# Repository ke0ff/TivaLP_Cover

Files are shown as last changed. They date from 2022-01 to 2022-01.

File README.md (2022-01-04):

# TivaLP_Cover
OpenSCAD case for the Tiva EK-TM4C123GXL LaunchPad

This is a 3-part enclosure for a TivaLP mated with a custom carrier board (AKA, shield board).  The two main parts are the Bottom and the Lid.  A third part is a clear or semi-clear light-pipe printed into the Lid.  This requires a printer with a multi-filament head in order to print as one piece.  Printing the light-pipe separately is an option, but would require a degree of manual finishing to the light-pipe and the receptor hole in the Lid.

Comments inside the OpenSCAD file describe how to create the three plots and also how to manipulate the file to produce fit-check "plots" where the pieces are all arranged in an "as assembled" fashion.

The carrier board is custom.  Details on this board are contained in the TivaLPS_HW folder.  The PCB can be fabricated using the included Gerber/NC data or the Altium database can be modified to create a custom shield board in the same form-factor as is required by the 3D case.

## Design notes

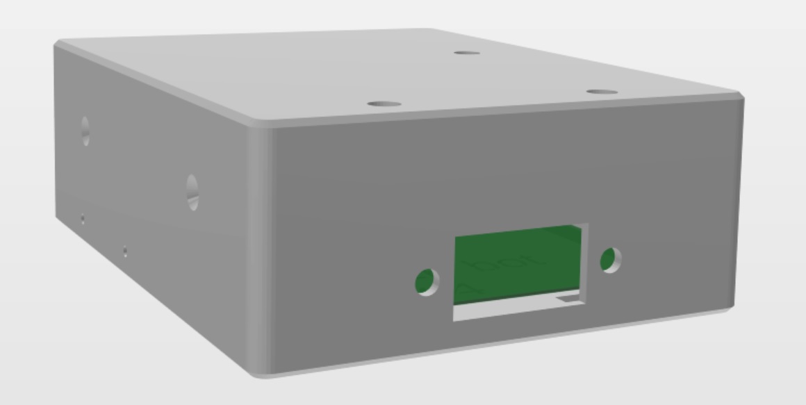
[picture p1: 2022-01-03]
TviaCaseV4.jpg

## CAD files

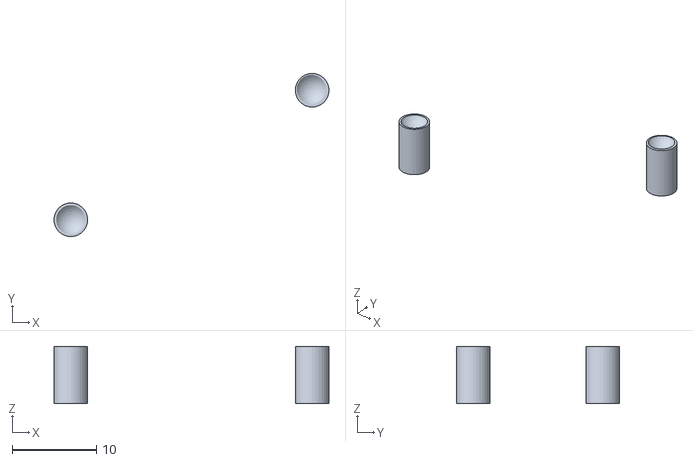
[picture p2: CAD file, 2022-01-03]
TivaCase_v4_lp.stl
32.7 x 19.4 x 6.80

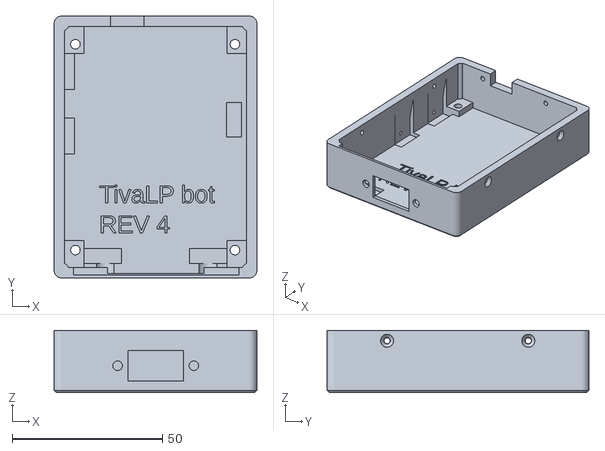
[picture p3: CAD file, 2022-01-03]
TivaCase_v4_bot.stl
67.5 x 87.2 x 20.8

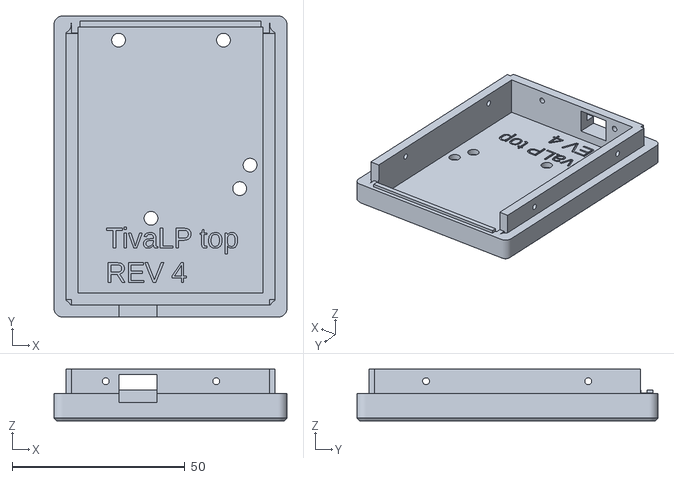
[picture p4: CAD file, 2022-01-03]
TivaCase_v4_top.stl
67.5 x 87.2 x 15.0

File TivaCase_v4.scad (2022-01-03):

// OpenSCAD 2019.05
// Tiva Case - enclosure, REV-001
// Joe Haas, KE0FF, 12/16/2021
// This is an enclosure for an EK-TM4C123GXL LaunchPad board and a custom LaunchPad
//	carrier board.
//
// Rev-004, 1/2/2022
//	Final adjustments from rev3 printing
//	added edge chamfers to top & bot at the platen faces of each part.  Softens the edge and
//		helps to counteract "elephant-foot" expansion.
//	increased depth of countersinks
//	increased size of USB port
//	removed SMA pilots for RF3&4 and replaced with "spot-face" that is 0.7mm thick
//	added another 0.5mm to lip0 for more edge clearance for LP board
//	Fixed 2-manifold rendering error in top piece (added 0.001mm to the "x" location
//		of the two corner rounds furthest from the rev text)
//
// Rev-003 (bot), 12/24/2021
//	(bot) added lid mtg countersinks (x6)
//
// Rev-003 (lid), 12/23/2021
//	(lid) added lip0 clips to remove interference
//
// Rev-002, 12/21/2021
//	incorporated fixes from first print run
//	increased lid thickness to provide room for stock LP board
//
// Rev-001, 12/16/2021
//	initial code -- copied from uxcover

//----------------------------------------------------------------------------------------------------------------------
// User defined parameters.  Modify these to suit a particular application
// NOTE: All data in this file is in mm
//----------------------------------------------------------------------------------------------------------------------
// parametric variables:

width = 67.5;
wcut = 10;
length = 87.2;
lcut = 10;
height = 20.8; //28.2;
heightl = 8;
lheight = 15;
wthick = 3.5;
wthickt = 1.5;
crad = 5;
crad2 = crad/2;
chamfer = .8;

////////////////////////////////////////////////////////////////////////////////
// Set each variable to "1" to render that part (!! only one part at a time !!).
// Set all = "0" to enable composite rendering (below).
plotlid = 1;
plotcase = 0;
plotlp = 0;

// these statements plot the 3D parts to print (one plot only, Visily!)
if(plotlid) lid(1);
if(plotlp) lid_lpipe();
if(plotcase) case();
////////////////////////////////////////////////////////////////////////////////

///////////////////////////////////////////////////////////
// Composite (debug) plot.  Places all elements in an
//	assembly orientation if no 3D parts are enabled (above)

if(!plotlid && !plotlp && !plotcase){
//	translate([0,0,0]) tiva_assy();						// launch-pad+carrier mockup for fit-check
	//
	// this is the complete case, oriented into an as-assembled view:
	difference(){
		union(){
			color("darkslategray",0.97) case();
			translate([0,length,height+heightl]) rotate([180,0,0]) color("darkslategray",1.0) lid(1);
			translate([0,length,height+heightl]) rotate([180,0,0]) lid_lpipe();
		}
//		translate([-1,-45,20.5]) cube([90,60,90]);		// cut-away viewing slice-cube (debug)
	}
}

//
//
//**************************************************
				//****************\\
				//    modules     \\
				//    follow      \\
				//****************\\
//**************************************************
//
//
///////////////
// Bottom shell

module case(){
	difference(){
		union(){
			difference(){
				union(){
					cube([width,length,height]);
//					translate([19.1,88,0]) cube([2,2,23.6]); // test-ruler
				}
 				translate([18.85,76,15.4]) cube([11,16,8.1]); 							// USB shroud
				cube([crad,crad,60], center=true);										// corner notch
				translate([width,0,0]) cube([crad,crad,60], center=true);				// corner notch
				translate([0,length,0]) cube([crad,crad,60], center=true);				// corner notch
				translate([width,length,0]) cube([crad,crad,60], center=true);			// corner notch
				translate([3.5,3.5,4.5]) cube([60.5,80.2,21.2]);						// main hog-out
				translate([3.5+6.5,3.5,4.5-2.5]) cube([60.5-13,80.2,5]);				// "Y" under PCB hog-out
				translate([3.5,3.5+6+3,4.5-2.5]) cube([60.5,80.2-12-6,5]);				// "X" under PCB hog-out
				translate([57.3,47,.5]) cube([5,11.4,4.5]);								// jtag port
				translate([width/2,length/2,11]) tiva_lp_mtg(10);						// pcb mtg holes
				translate([width/2,length/2,0]) tiva_lp_mtg_cs();						// pcb mtg hole counter-sinks
				translate([.08+(width/2),1.5,9]) rotate([270,0,0]) db9();				// DB9 cutout
				translate([width/2,length/2,11]) sma_pilot();							// sma pilots (RF3 & RF4)
				translate([width/2,length/2,11]) sma2_pilot();							// sma pilots, RF2
				translate([width/2,length/2+21.4,11]) sma2_pilot();						// sma pilots, RF1
				translate([6.5,1.0,15.5]) cube([width-12.5,4,6]);						// tiva groove
			}
			translate([crad2,crad2,0]) corner(height);									// corner radius (x4)
			translate([width-crad2,crad2,0]) corner(height);
			translate([crad2,length-crad2,0]) corner(height);
			translate([width-crad2,length-crad2,0]) corner(height);
		}
		translate([15,length-4,17.3]) pilot();											// pilot
		translate([47,length-4,17.3]) pilot();											// pilot
		translate([15,length,17.3]) rotate([90,0,0]) cs(2);								// side countersinks
		translate([47,length,17.3]) rotate([90,0,0]) cs(2);								// side countersinks

		translate([4,20,17.3]) rotate([0,0,90]) pilot();								// pilot
		translate([4,67,17.3]) rotate([0,0,90]) pilot();								// pilot
		translate([0,20,17.3]) rotate([0,90,0]) cs(2);									// side countersinks
		translate([0,67,17.3]) rotate([0,90,0]) cs(2);									// side countersinks

		translate([width-4,20,17.3]) rotate([0,0,90]) pilot();							// pilot
		translate([width-4,67,17.3]) rotate([0,0,90]) pilot();							// pilot
		translate([width,20,17.3]) rotate([0,270,0]) cs(2);								// side countersinks
		translate([width,67,17.3]) rotate([0,270,0]) cs(2);								// side countersinks

		translate([15,15,1.5]) linear_extrude(1) text("REV 4", size=6);					// version & PN texts
		translate([15,25,1.5]) linear_extrude(1) text("TivaLP bot", size=6);
		
		translate([0,chamfer,-.01]) rotate([135,0,0]) cube([width+10,5,5]);				// edge chams
		translate([0,length-chamfer,-.01]) rotate([-45,0,0]) cube([width+10,5,5]);
		translate([chamfer,0,-.01]) rotate([0,360-135,0]) cube([5,length+10,5]);
		translate([width-chamfer,0,-.01]) rotate([0,45,0]) cube([5,length+10,5]);
	}
}

////////////
// Top cover

module lid(hole){
	difference(){
		union(){
			difference(){
				union(){
					cube([width,length,heightl]);													// main lid
				}
				cube([crad,crad,60], center=true);													// corner nibble
				translate([width,0,0]) cube([crad,crad,60], center=true);							// corner nibble
				translate([0,length,0]) cube([crad,crad,60], center=true);							// corner nibble
				translate([width,length,0]) cube([crad,crad,60], center=true);						// corner nibble
				translate([wthick,wthick,2]) cube([60.5,80.2+wthickt,21.2]);						// main hog-out
				translate([0,length,(height)]) rotate([180,0,0]) tiva_assy(1);		// "1" param burns button/LP holes
			}
			translate([wcut/2,wthick,0]) cube([width-wcut,wthick,lheight]);							// lip
			translate([wcut/2,length-(wthick/2)-(wthickt)-.001,1]) cube([width-wcut,wthick/2,8]);	// lip0
			translate([wcut/2,length-(wthick/2)-(wthickt)-2,1]) cube([2,2.1,8]);					// lip0 tie-in
			translate([width-(wthick*2),length-(wthick/2)-(wthickt)-2,1]) cube([2,2.1,8]);			// lip0 tie-in
			translate([wthick,wcut/2,0]) cube([wthick,length-wcut,lheight]);						// lip
			translate([width-(2*wthick),wcut/2,0]) cube([wthick,length-wcut,lheight]);				// lip
//	corner(heightl);
			translate([crad2,crad2,0]) corner(heightl);												// corner
			translate([width-crad2,crad2,0]) corner(heightl);	// corner
			translate([crad2+.001,length-crad2,0]) corner(heightl);	// corner
			translate([width-crad2+.001,length-crad2,0]) corner(heightl);	// corner
		}
		translate([18.85,-1,lheight-1.7-8]) cube([11,16,8.1]);										// USB housing
		translate([15,4,lheight-3.5]) pilot();														// pilot
		translate([47,4,lheight-3.5]) pilot();														// pilot
		translate([4,20,lheight-3.5]) rotate([0,0,90]) pilot();										// pilot
		translate([4,67,lheight-3.5]) rotate([0,0,90]) pilot();										// pilot
		translate([width-4,20,lheight-3.5]) rotate([0,0,90]) pilot();								// pilot
		translate([width-4,67,lheight-3.5]) rotate([0,0,90]) pilot();								// pilot
		translate([2.5,82.21,8.01]) cube([5,5,3]);													// corner clearance @ lip0
		translate([60,82.21,8.01]) cube([5,5,3]);													// corner clearance @ lip0
		translate([15,10,1.5]) linear_extrude(1) text("REV 4", size=6);								// version and PN texts
		translate([15,20,1.5]) linear_extrude(1) text("TivaLP top", size=6);

		translate([0,chamfer,-.01]) rotate([135,0,0]) cube([width+10,5,5]);							// edge chams
		translate([0,length-chamfer,-.01]) rotate([-45,0,0]) cube([width+10,5,5]);
		translate([chamfer,0,-.01]) rotate([0,360-135,0]) cube([5,length+10,5]);
		translate([width-chamfer,0,-.01]) rotate([0,45,0]) cube([5,length+10,5]);
	}
}

/////////////////////////////////////
// Light pipe (inserts into top cover)
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

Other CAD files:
TivaCase.scad
TivaCase_v3.scad

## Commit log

2021-12-17 Initial Commit
    The zip file contains the latest stl output files
    [TivaCase.scad]
2021-12-22 Rev-002 Commit
    Extended the lid to make room for top-side LaunchPad artifacts. Added opening for debug USB connection. Cleaned up button and light-pipe locations. Added slopes for the SMA1 & 2 openings. Added PN an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
    [TivaCase_v2.scad]
2021-12-24 Rev-003 of lid stl
    added corner clips to remove interference
    [TivaCase_v3.scad, TivaCase_v3_lid.stl]
2021-12-24 V3 Bottom
    Added countersinks to the lid mtg holes. General source file cleanup.
    [TivaCase_v3.scad, TivaCase_v3_bot.stl]
2022-01-03 Rev4 commit
    // added edge chamfers to top & bot at the platen faces of each part. Softens the edge and
    // helps to counteract "elephant-foot" expansion.
    // increased depth of countersinks
    // increased size of USB port
    // removed SMA pilots for RF3&4 and replaced with "spot-face" that is 0.7mm thick
    // added another 0.5mm to lip0 for more edge clearance for LP board
    // Fixed 2-manifold rendering error in top piece (added 0.001mm to the "x" location of the two corner rounds furthest from the rev text)
    [TivaCase_v4.scad, TivaCase_v4_bot.stl, TivaCase_v4_top.stl]
2022-01-03 Initial commit
    V4 3D PDF (reference view of complete case)
2022-01-03 V4 commit
    [TivaCase_v4_lp.stl]
2022-01-04 Initial Commit
    Tiva LaunchPad shield hardware design. Includes Altium database, Gerber outputs, and PDF schematic. TivaLPS_3D.pdf is a 3DPDF of the design (viewable using current revisions of the Adobe PDF reader).
2022-01-04 Added Drill Dwg PDF
2022-01-04 Added drill drawing pdf
